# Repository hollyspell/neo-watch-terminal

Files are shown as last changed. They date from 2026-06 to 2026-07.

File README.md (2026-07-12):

# NEO WATCH Terminal

A retro Mission Control–style e-ink terminal that tracks near-Earth objects using NASA's open APIs.

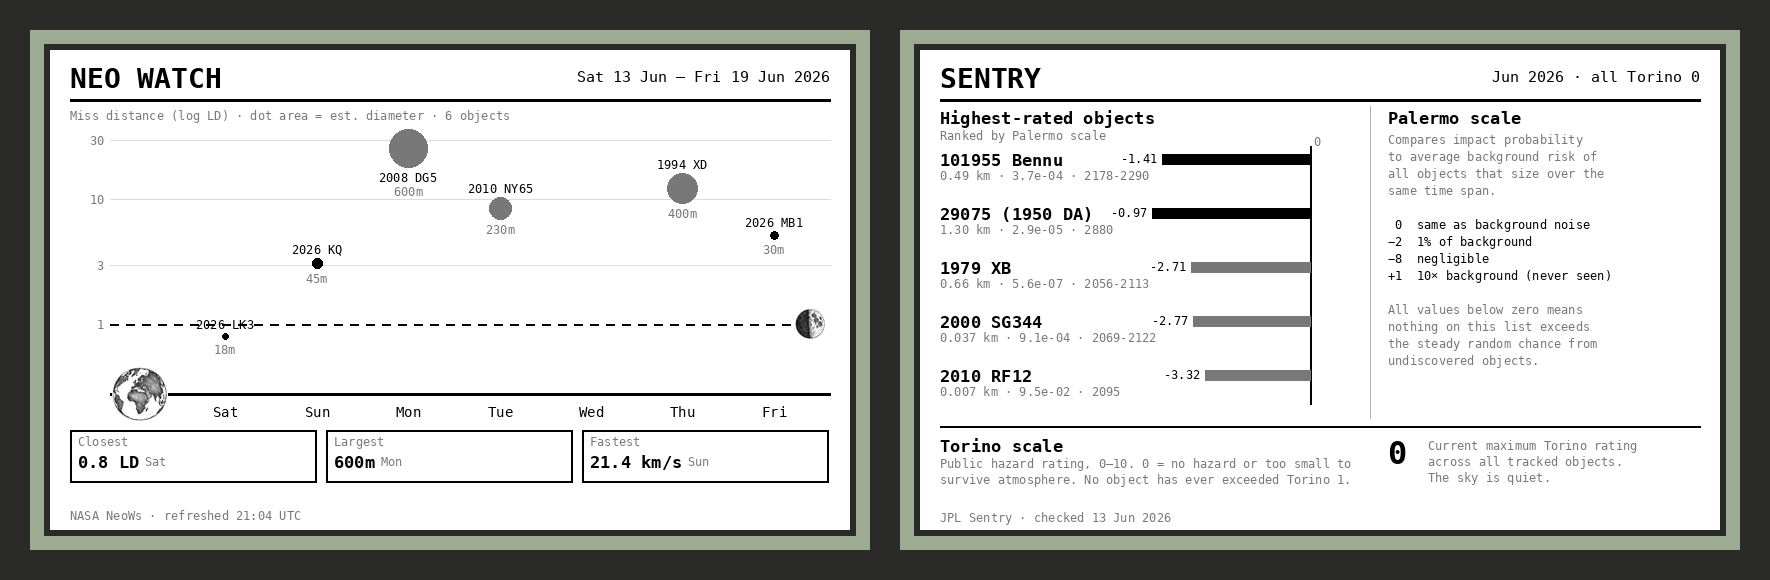
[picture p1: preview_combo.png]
Both screens preview


## What it is

A 3D-printed terminal with a 7.5" e-ink display, powered by a Raspberry Pi Zero, showing two views toggled by a single square push button:

- **NEO WATCH** — this week's asteroid close approaches plotted by distance and day
- **SENTRY** — JPL's impact risk watch list with Palermo and Torino scale ratings

Minimal soldering — four small wire-to-wire joints on the button leads.
Everything else is push-on.

## Quick start

```bash
# On your Pi (after flashing Raspberry Pi OS Lite 32-bit and enabling SPI):
sudo apt install -y git python3-pip python3-pil python3-numpy \
                    python3-rpi.gpio python3-spidev python3-requests \
                    python3-lgpio fonts-dejavu-core

git clone https://github.com/waveshare/e-Paper.git
cd e-Paper/RaspberryPi_JetsonNano/python && pip3 install . --break-system-packages && cd ~

git clone https://github.com/hollyspell/neo-watch-terminal.git
cd neo-watch-terminal

# Get a free key at https://api.nasa.gov — DEMO_KEY is only 30/hr and 50/day
export NASA_API_KEY="your_key_here"

python3 neo_eink.py
```

## Preview without hardware

```bash
# On any computer with Python 3 and Pillow:
pip install pillow requests
python3 neo_eink.py --preview         # live API data → PNG files
python3 neo_eink.py --preview --mock  # mock data → PNG files (no network needed)
```

## Documentation

See the [wiki](../../wiki) for the full build guide:

- [Bill of Materials](../../wiki/Bill-of-Materials) — shopping list with links
- [Printing Guide](../../wiki/Printing-Guide) — STL settings and finishing
- [Hardware Assembly](../../wiki/Hardware-Assembly) — no-solder assembly instructions
- [Software Setup](../../wiki/Software-Setup) — flashing, installing, auto-start
- [Display Design](../../wiki/Display-Design) — visualization design and customization
- [Troubleshooting](../../wiki/Troubleshooting) — common issues and fixes

## Files

| File | Description |
|---|---|
| `neo_eink.py` | Main firmware — fetches APIs, renders views, drives display, handles button |
| `earth_bitmap.png` | Pen-and-ink Earth illustration, pre-processed for e-ink |
| `moon_bitmap.png` | Pen-and-ink Moon illustration, pre-processed for e-ink |
| `terminal.py` | Parametric enclosure generator (Manifold3D + trimesh) |
| `eink_terminal.stl` | Printable enclosure body |
| `eink_plate.stl` | Printable slide-in bottom panel |

## Before you build

Two things that will save you a day:

- **The HAT's Display Config switch must be on `B`** (Interface Config `0`).
  Set wrong, the display runs every demo with zero errors and shows nothing at all.
- **The button goes on GPIO 26, not GPIO 17.** GPIO 17 is the display's reset line.

See [Troubleshooting](../../wiki/Troubleshooting) if the panel stays blank.

## Data sources

- [NASA NeoWs](https://api.nasa.gov/) — near-Earth object close approach data
- [JPL Sentry](https://cneos.jpl.nasa.gov/sentry/) — impact risk monitoring

## License

MIT License

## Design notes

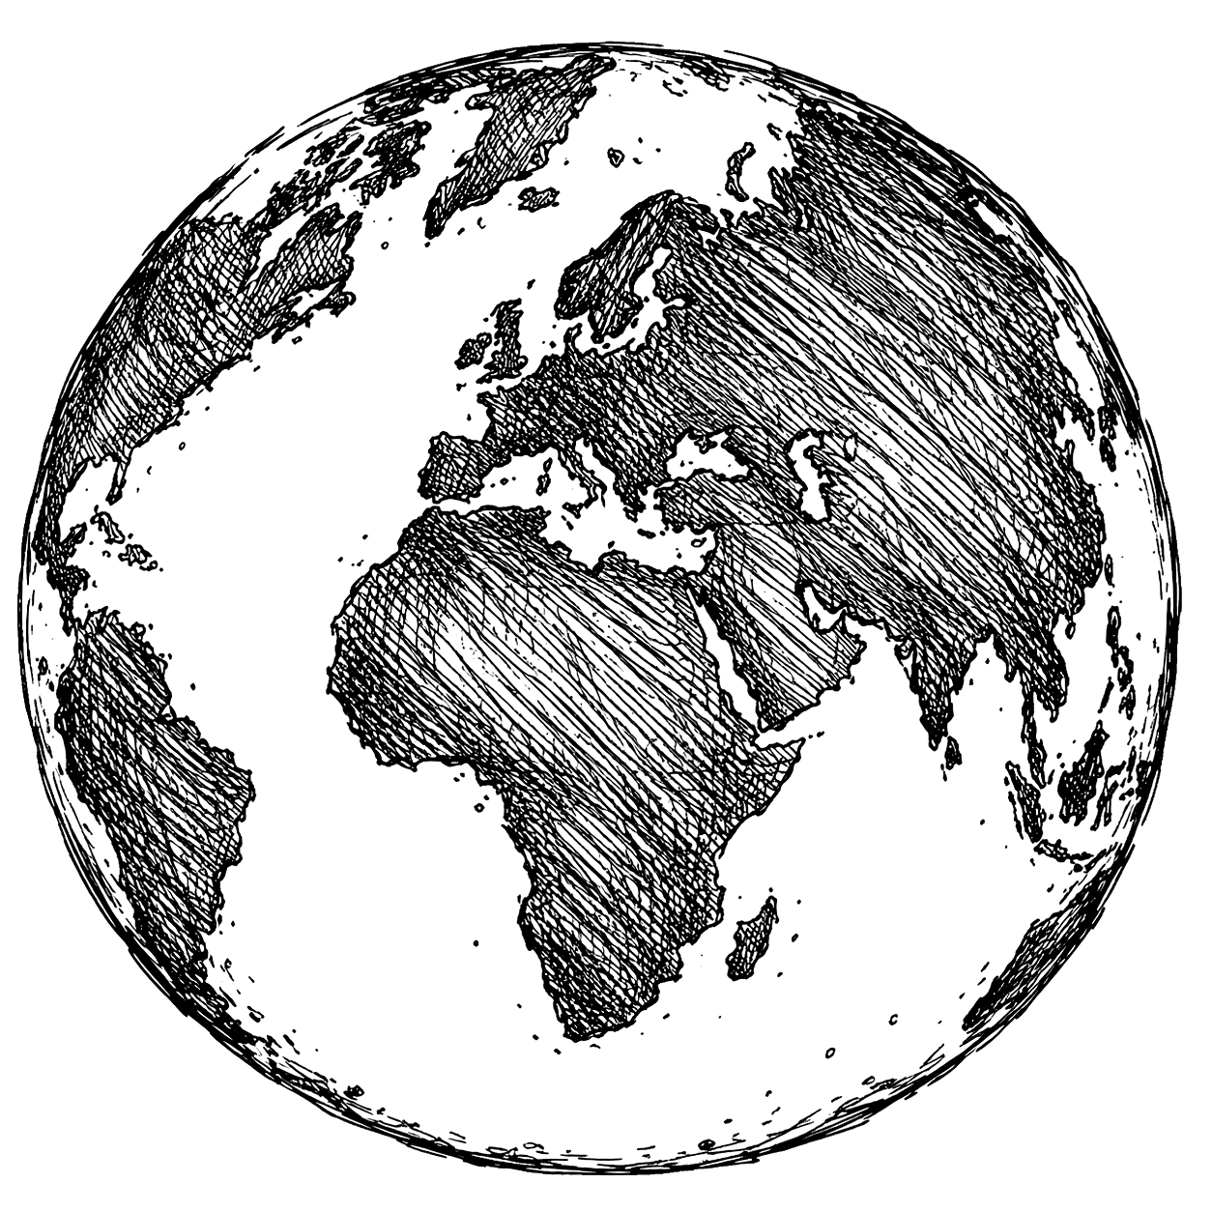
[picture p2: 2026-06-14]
earth_bitmap.png

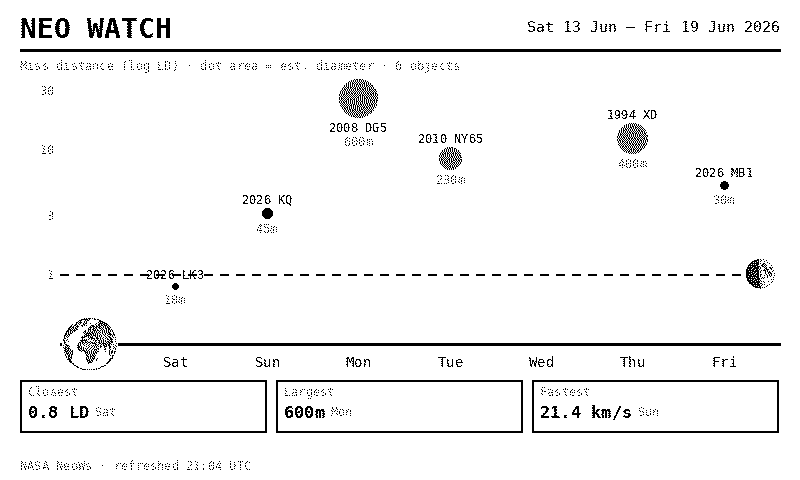
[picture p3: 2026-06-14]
neo_watch_1bit.png

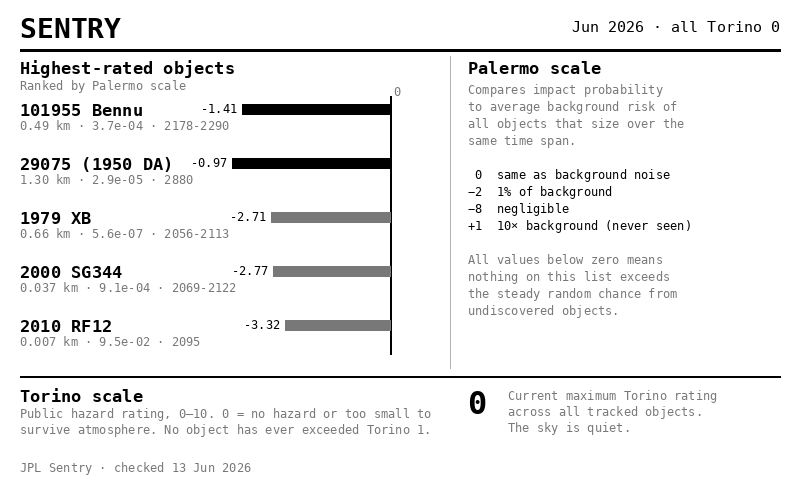
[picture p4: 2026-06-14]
sentry_gray.png

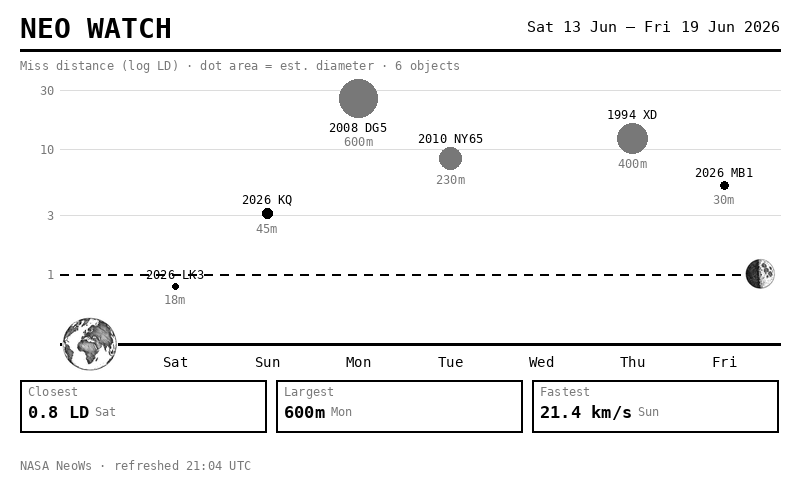
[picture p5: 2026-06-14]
neo_watch_gray.png

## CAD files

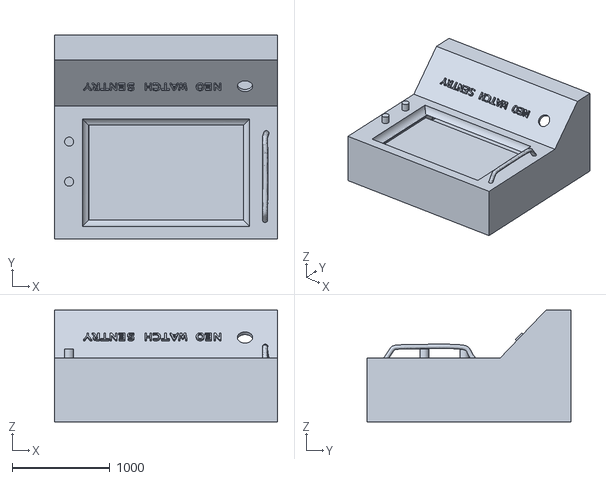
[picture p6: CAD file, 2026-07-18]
terminal test2.stl
2282.6 x 2092.3 x 1143.0

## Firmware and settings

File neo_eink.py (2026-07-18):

#!/usr/bin/env python3
"""
NEO WATCH / SENTRY — dual-view e-ink terminal firmware.

Renders two 800×480 1-bit images for a Waveshare 7.5" e-ink panel:
  View 1: NEO WATCH  — this week's close approaches (NASA NeoWs)
  View 2: SENTRY     — JPL Sentry risk-list objects with Palermo/Torino

Preview mode (no Pi hardware):
    python neo_eink.py --preview

Hardware mode (Raspberry Pi + Waveshare 7.5" v2):
    python neo_eink.py
    (button on GPIO 26 toggles views)

NASA API key: uses DEMO_KEY by default (30 req/hr AND 50 req/day).
Set NASA_API_KEY env var for a free personal key (1000 req/day).
Note: systemd does not read ~/.bashrc — the service unit needs its own
Environment=NASA_API_KEY=... line.
"""

import json, math, os, sys, time, argparse
from datetime import datetime, timedelta
from io import BytesIO
from pathlib import Path

import requests
from PIL import Image, ImageDraw, ImageFont

# ─── Configuration ────────────────────────────────────────────────────
W, H = 800, 480  # Waveshare 7.5" v2 resolution
NASA_KEY = os.environ.get("NASA_API_KEY", "DEMO_KEY")
NEOWS_URL = "https://api.nasa.gov/neo/rest/v1/feed"
_neows_quota = None  # X-RateLimit-Remaining from the most recent NeoWs call
SENTRY_URL = "https://ssd-api.jpl.nasa.gov/sentry.api"

FONT_REG = "/usr/share/fonts/truetype/dejavu/DejaVuSansMono.ttf"
FONT_BOLD = "/usr/share/fonts/truetype/dejavu/DejaVuSansMono-Bold.ttf"

# Preload fonts at sizes we need
def font(size, bold=False):
    return ImageFont.truetype(FONT_BOLD if bold else FONT_REG, size)

F32 = font(28, bold=True)
F20 = font(17)
F20B = font(17, bold=True)
F18 = font(15)
F16 = font(14)
F14 = font(12)
F24 = font(21, bold=True)
F36 = font(32, bold=True)

BLACK = 0
WHITE = 255
GRAY = 30  # dark enough to survive 1-bit dither as readable stipple

# ─── API fetching ─────────────────────────────────────────────────────

def fetch_neows():
    """Fetch this week's near-Earth object close approaches.

    Returns (objects, start, end). `objects` is None on a real failure, or a
    list (possibly empty) on success — the two states render differently.
    """
    today = datetime.utcnow().date()
    end = today + timedelta(days=6)
    params = {
        "start_date": today.isoformat(),
        "end_date": end.isoformat(),
        "api_key": NASA_KEY,
    }
    global _neows_quota
    try:
        r = requests.get(NEOWS_URL, params=params, timeout=30)
        r.raise_for_status()
        data = r.json()
        _neows_quota = r.headers.get("X-RateLimit-Remaining")
        if _neows_quota:
            print(f"  NeoWs quota remaining: {_neows_quota}")
    except Exception as e:
        print(f"NeoWs fetch failed: {e}")
        return None, today, end

    objects = []
    for date_str, neos in data.get("near_earth_objects", {}).items():
        for neo in neos:
            ca = neo["close_approach_data"][0] if neo.get("close_approach_data") else None
            if not ca:
                continue
            dia = neo.get("estimated_diameter", {}).get("meters", {})
            avg_dia = (dia.get("estimated_diameter_min", 0) + dia.get("estimated_diameter_max", 0)) / 2
            miss_ld = float(ca["miss_distance"]["lunar"])
            objects.append({
                "name": neo.get("name", "?").strip("() "),
                "date": date_str,
                "miss_ld": miss_ld,
                "miss_km": float(ca["miss_distance"]["kilometers"]),
                "diameter_m": avg_dia,
                "velocity_kms": float(ca["relative_velocity"]["kilometers_per_second"]),
                "hazardous": neo.get("is_potentially_hazardous_asteroid", False),
            })
    # Keep only passes within 35 LD and sort by date
    objects = [o for o in objects if o["miss_ld"] <= 35]
    objects.sort(key=lambda o: (o["date"], o["miss_ld"]))
    return objects, today, end


def fetch_sentry():
    """Fetch JPL Sentry risk list, sorted by Palermo scale (descending)."""
    try:
        r = requests.get(SENTRY_URL, timeout=30)
        r.raise_for_status()
        data = r.json()
    except Exception as e:
        print(f"Sentry fetch failed: {e}")
        return None

    items = []
    for obj in data.get("data", []):
        ps = float(obj.get("ps_cum") or -99)
        ts = int(float(obj.get("ts_max") or 0))
        dia = obj.get("diameter", "?")
        ip = obj.get("ip", "?")
        name = obj.get("fullname", obj.get("des", "?")).strip()
        yr_range = obj.get("range", "?")
        items.append({
            "name": name,
            "palermo": ps,
            "torino": ts,
            "diameter_km": dia,
            "impact_prob": ip,
            "year_range": yr_range,
        })
    items.sort(key=lambda x: x["palermo"], reverse=True)
    return items


# ─── Drawing helpers ──────────────────────────────────────────────────

# ─── Ink illustration bitmaps for Earth & Moon ────────────────────────

# Pre-processed circular bitmaps from pen-and-ink illustrations
EARTH_BMP = os.path.join(os.path.dirname(__file__), "earth_bitmap.png")
MOON_BMP = os.path.join(os.path.dirname(__file__), "moon_bitmap.png")

_bitmap_cache = {}

def _load_bitmap(bmp_path, size):
    """Load a pre-rendered bitmap and resize to target."""
    key = (bmp_path, size)
    if key in _bitmap_cache:
        return _bitmap_cache[key]
    try:
        img = Image.open(bmp_path).convert("L")
        img = img.resize((size, size), Image.LANCZOS)
    except FileNotFoundError:
        img = Image.new("L", (size, size), WHITE)
        d = ImageDraw.Draw(img)
        d.ellipse([2, 2, size-3, size-3], fill=BLACK)
        print(f"Bitmap not found: {bmp_path} — using fallback")
    _bitmap_cache[key] = img
    return img


def paste_earth(target_img, cx, cy, diameter):
    """Paste the ink-illustration Earth onto a grayscale image."""
    bmp = _load_bitmap(EARTH_BMP, diameter)
    x = cx - diameter // 2
    y = cy - diameter // 2
    target_img.paste(bmp, (x, y))


def paste_moon(target_img, cx, cy, diameter):
    """Paste the ink-illustration Moon, phase-shaded, onto a grayscale image."""
    bmp = apply_moon_phase(_load_bitmap(MOON_BMP, diameter), moon_phase_fraction())
    x = cx - diameter // 2
    y = cy - diameter // 2
    target_img.paste(bmp, (x, y))


# ─── Moon phase (pure math, no API) ──────────────────────────────────

def _julian_day(dt):
    y, m = dt.year, dt.month
    d = dt.day + (dt.hour + dt.minute/60 + dt.second/3600)/24
    if m <= 2:
        y -= 1; m += 12
    a = y // 100
    b = 2 - a + a//4
    return int(365.25*(y+4716)) + int(30.6001*(m+1)) + d + b - 1524.5


def moon_phase_fraction(dt=None):
    """0.0 = new, 0.25 = first quarter, 0.5 = full, 0.75 = last quarter.

    Meeus (Astronomical Algorithms ch.48) low-precision phase angle — accounts
    for the Moon's elliptical orbit, unlike a mean-synodic approximation.
    Accurate to well under 1% illumination. No network required.
    """
    if dt is None:
        dt = datetime.utcnow()
    T = (_julian_day(dt) - 2451545.0) / 36525.0
    D_deg = (297.8501921 + 445267.1114034*T - 0.0018819*T*T) % 360
    M  = math.radians((357.5291092 + 35999.0502909*T - 0.0001536*T*T) % 360)
    Mp = math.radians((134.9633964 + 477198.8675055*T + 0.0087414*T*T) % 360)
    D  = math.radians(D_deg)
    i = (180 - D_deg
         - 6.289*math.sin(Mp) + 2.100*math.sin(M)
         - 1.274*math.sin(2*D - Mp) - 0.658*math.sin(2*D)
         - 0.214*math.sin(2*Mp) - 0.110*math.sin(D)) % 360
    k = (1 + math.cos(math.radians(i))) / 2          # illuminated fraction
    a = math.acos(max(-1.0, min(1.0, 1 - 2*k))) / (2*math.pi)
    return a if D_deg < 180 else 1 - a                # D<180 = waxing

_lit_cache = {}

def _lit_version(moon_img):
    """Sunlit rendering of the moon: craters kept, disk background lifted to white."""
    key = (moon_img.width, moon_img.tobytes())
    if key in _lit_cache:
        return _lit_cache[key]
    size = moon_img.width
    r = size / 2.0
    px = moon_img.load()
    vals = [px[x, y]
            for y in range(size) for x in range(size)
            if (x - r + 0.5)**2 + (y - r + 0.5)**2 < (r - 1)**2]
    if not vals:
        return moon_img
    vals.sort()
    base = vals[len(vals)//2]            # median ≈ the disk's background tone
    T = max(1, int(base * 0.98))
    out = moon_img.point(lambda v: 255 if v >= T else v)
    _lit_cache[key] = out
    return out


def apply_moon_phase(moon_img, fraction):
    """Shade the moon bitmap by phase.

    Sunlit side  → craters on white (the disk's grey background lifted out).
    Shadowed side → the illustration as-is, grey fill and all.
    So a new moon is fully shaded and a full moon is craters on blank white.
    """
    size = moon_img.width
    r = size / 2.0
    shadow = moon_img
    lit = _lit_version(moon_img)

    mask = Image.new("L", (size, size), 0)
    md = ImageDraw.Draw(mask)
    c = math.cos(2 * math.pi * fraction)
    waxing = fraction < 0.5
    for py in range(size):
        y = py - r + 0.5
        if abs(y) >= r:
            continue
        x_e = math.sqrt(r * r - y * y)
        if waxing:
            lit_lo, lit_hi = c * x_e, x_e      # lit on the right
        else:
            lit_lo, lit_hi = -x_e, -c * x_e    # lit on the left
        if lit_hi > lit_lo:
            md.line([(r + lit_lo, py), (r + lit_hi, py)], fill=255)

    out = Image.composite(lit, shadow, mask)
    ImageDraw.Draw(out).ellipse([0, 0, size - 1, size - 1], outline=BLACK, width=1)
    return out

def ld_to_y(ld, y_top, y_bottom):
    """Map lunar distance (log scale) to y pixel. ld in [0.3, 35] → [y_bottom, y_top]."""
    if ld <= 0:
        ld = 0.3
    log_min, log_max = math.log10(0.3), math.log10(35)
    frac = (math.log10(ld) - log_min) / (log_max - log_min)
    return int(y_bottom - frac * (y_bottom - y_top))


def dia_to_radius(dia_m):
    """Object diameter (meters) → dot radius in pixels (sqrt scale, clamped)."""
    r = max(3, min(22, int(2.5 * math.sqrt(dia_m / 10))))
    return r


# ─── View 1: NEO WATCH ───────────────────────────────────────────────

def render_neo_watch(objects, date_start, date_end):
    img = Image.new("L", (W, H), WHITE)
    draw = ImageDraw.Draw(img)

    # ── Header ──
    draw.text((20, 12), "NEO WATCH", font=F32, fill=BLACK)
    date_str = f"{date_start.strftime('%a %d %b')} – {date_end.strftime('%a %d %b %Y')}"
    bbox = draw.textbbox((0, 0), date_str, font=F18)
    draw.text((W - 20 - (bbox[2] - bbox[0]), 18), date_str, font=F18, fill=BLACK)
    draw.line([(20, 50), (W-20, 50)], fill=BLACK, width=3)

    # ── Subtitle ──
    count = len(objects) if objects else 0
    sub = f"Miss distance (log LD) · dot area = est. diameter · {count} objects"
    draw.text((20, 58), sub, font=F14, fill=GRAY)

    # ── Chart area ──
    chart_left = 60
    chart_right = W - 20
    chart_top = 82
    chart_bot = 340
    earth_x = chart_left + 30

    # Grid lines
    for ld_val, label in [(30, "30"), (10, "10"), (3, "3")]:
        y = ld_to_y(ld_val, chart_top, chart_bot)
        draw.line([(chart_left, y), (chart_right, y)], fill=220, width=1)
        bbox = draw.textbbox((0, 0), label, font=F14)
        draw.text((chart_left - 6 - (bbox[2]-bbox[0]), y - 7), label, font=F14, fill=GRAY)

    # Moon line at 1 LD
    moon_y = ld_to_y(1.0, chart_top, chart_bot)
    # Dashed line
    dash_len = 8
    for x in range(chart_left, chart_right, dash_len * 2):
        draw.line([(x, moon_y), (min(x + dash_len, chart_right), moon_y)], fill=BLACK, width=2)
    draw.text((chart_left - 6 - draw.textbbox((0,0), "1", font=F14)[2], moon_y - 7),
              "1", font=F14, fill=GRAY)

    # Earth baseline
    draw.line([(chart_left, chart_bot + 4), (chart_right, chart_bot + 4)], fill=BLACK, width=3)

    # Draw Earth
    paste_earth(img, earth_x, chart_bot + 4, 56)

    # Draw Moon
    moon_x = chart_right - 20
    paste_moon(img, moon_x, moon_y, 32)

    # ── Day columns ──
    if objects and date_start:
        days = [(date_start + timedelta(days=i)) for i in range(7)]
        day_labels = [d.strftime("%a") for d in days]
        day_strs = [d.isoformat() for d in days]

        col_width = (chart_right - chart_left - 80) / 7  # leave room for earth & moon
        col_starts = [chart_left + 70 + int(i * col_width + col_width / 2) for i in range(7)]

        # Day labels below baseline
        for i, (lbl, cx) in enumerate(zip(day_labels, col_starts)):
            bbox = draw.textbbox((0, 0), lbl, font=F16)
            draw.text((cx - (bbox[2]-bbox[0])//2, chart_bot + 14), lbl, font=F16, fill=BLACK)

        # Plot objects — group by day, jitter within column if needed
        day_objects = {ds: [] for ds in day_strs}
        for obj in objects:
            if obj["date"] in day_objects:
                day_objects[obj["date"]].append(obj)

        for i, ds in enumerate(day_strs):
            objs = day_objects.get(ds, [])
            cx = col_starts[i]
            for j, obj in enumerate(objs):
                y = ld_to_y(obj["miss_ld"], chart_top, chart_bot)
                r = dia_to_radius(obj["diameter_m"])
                # Jitter horizontally if multiple on same day
                jitter = (j - len(objs)/2) * (r + 4) if len(objs) > 1 else 0
                ox = int(cx + jitter)
                oy = y

                fill = GRAY if obj.get("hazardous") else BLACK
                draw.ellipse([ox-r, oy-r, ox+r, oy+r], fill=fill)

                # Label — short name
                name = obj["name"]
                # Shorten long names
                if len(name) > 10:
                    parts = name.split()
                    name = parts[-1] if len(parts) > 1 else name[:8]
                bbox = draw.textbbox((0, 0), name, font=F14)
                tw = bbox[2] - bbox[0]
                label_y = oy - r - 16
                if label_y < chart_top:
                    label_y = oy + r + 3
                draw.text((ox - tw//2, label_y), name, font=F14, fill=BLACK)

                # Size label below
                if obj["diameter_m"] >= 10:
                    size_str = f"{int(obj['diameter_m'])}m"
                    bbox2 = draw.textbbox((0, 0), size_str, font=F14)
                    sw = bbox2[2] - bbox2[0]
                    sz_y = oy + r + 3
                    if label_y == oy + r + 3:
                        sz_y = label_y + 14
                    if sz_y < chart_bot - 2:
                        draw.text((ox - sw//2, sz_y), size_str, font=F14, fill=GRAY)
    else:
        # Distinguish "the sky was quiet" from "the fetch actually failed".
        # fetch_neows() returns None on failure, [] on a successful quiet week.
        if objects is None:
            msg = "No data — check API"
        else:
            msg = "No close approaches this week"
        bbox = draw.textbbox((0, 0), msg, font=F20)
        draw.text(((W - (bbox[2]-bbox[0])) // 2, 200), msg, font=F20, fill=BLACK)

    # ── Stat boxes ──
    box_y = chart_bot + 40
    box_h = 52
    box_w = (W - 60) // 3

    stats = _compute_stats(objects)
    for i, (label, value, sub) in enumerate(stats):
        bx = 20 + i * (box_w + 10)
        draw.rectangle([bx, box_y, bx + box_w, box_y + box_h], outline=BLACK, width=2)
        draw.text((bx + 8, box_y + 4), label, font=F14, fill=GRAY)
        draw.text((bx + 8, box_y + 22), value, font=F20B, fill=BLACK)
        # Sub text (day) to right of value
        vbbox = draw.textbbox((0, 0), value, font=F20B)
        draw.text((bx + 14 + (vbbox[2]-vbbox[0]), box_y + 24), sub, font=F14, fill=GRAY)

    # ── Footer ──
    footer = "NASA NeoWs · refreshed " + time.strftime("%H:%M %Z")
    if _neows_quota:
        footer += f" · {_neows_quota} API calls left today"
    draw.text((20, H - 22), footer, font=F14, fill=GRAY)

    return img


def _compute_stats(objects):
    if not objects:
        return [("Closest", "—", ""), ("Largest", "—", ""), ("Fastest", "—", "")]
    closest = min(objects, key=lambda o: o["miss_ld"])
    largest = max(objects, key=lambda o: o["diameter_m"])
    fastest = max(objects, key=lambda o: o["velocity_kms"])
    c_day = datetime.fromisoformat(closest["date"]).strftime("%a")
    l_day = datetime.fromisoformat(largest["date"]).strftime("%a")
    f_day = datetime.fromisoformat(fastest["date"]).strftime("%a")
    return [
        ("Closest", f"{closest['miss_ld']:.1f} LD", c_day),
        ("Largest", f"{int(largest['diameter_m'])}m", l_day),
        ("Fastest", f"{fastest['velocity_kms']:.1f} km/s", f_day),
    ]


# ─── View 2: SENTRY ──────────────────────────────────────────────────

def fmt_ip(ip_raw):
    """Impact probability -> compact scientific notation, e.g. 5.7e-04."""
    try:
        return f"{float(ip_raw):.1e}"
    except (TypeError, ValueError):
        return "?"


def fmt_years(yr):
    """Collapse degenerate ranges: '2880-2880' -> '2880'."""
    if isinstance(yr, str) and "-" in yr:
        a, b = yr.split("-", 1)
        if a.strip() == b.strip():
            return a.strip()
    return yr


def render_sentry(items):
    img = Image.new("L", (W, H), WHITE)
    draw = ImageDraw.Draw(img)

    max_torino = 0
    if items:
        max_torino = max(it["torino"] for it in items)
    draw.text((20, 12), "SENTRY", font=F32, fill=BLACK)
    torino_str = time.strftime("%b %Y") + f" · all Torino {max_torino}"
    bbox = draw.textbbox((0, 0), torino_str, font=F18)
    draw.text((W - 20 - (bbox[2]-bbox[0]), 18), torino_str, font=F18, fill=BLACK)
    draw.line([(20, 50), (W-20, 50)], fill=BLACK, width=3)

    # ── Left panel: ranked objects ──
    mid_x = 450
    draw.text((20, 58), "Highest-rated objects", font=F20B, fill=BLACK)
    draw.text((20, 78), "Ranked by Palermo scale", font=F14, fill=BLACK)

    # Bar lane: names own [20, name_right]; bars own their own lane after it
    name_right = 250
    bar_lane_left = name_right + 60   # room for value labels left of short bars
    zero_x = mid_x - 20
    bar_max = zero_x - bar_lane_left
    bar_top = 100
    bar_spacing = 54

    n_show = min(5, len(items) if items else 0)
    if n_show > 0:
        draw.line([(zero_x, bar_top - 4), (zero_x, bar_top + n_show * bar_spacing - 16)],
                  fill=BLACK, width=2)
        draw.text((zero_x + 4, bar_top - 16), "0", font=F14, fill=BLACK)

    top_items = items[:n_show] if items else []
    for i, it in enumerate(top_items):
        y = bar_top + i * bar_spacing
        # Name — shrink to fit its column, truncate only as last resort
        name = it["name"]
        f_name = F20B
        if draw.textbbox((0, 0), name, font=f_name)[2] > name_right - 20:
            f_name = F16
            while name and draw.textbbox((0, 0), name, font=f_name)[2] > name_right - 20:
                name = name[:-1]
        draw.text((20, y), name, font=f_name, fill=BLACK)
        # Details line
        dia_str = it["diameter_km"]
        if isinstance(dia_str, str):
            detail = f"{dia_str} km"
        else:
            detail = f"{float(dia_str):.2f} km"
        detail += f" · {fmt_ip(it['impact_prob'])} · {fmt_years(it['year_range'])}"
        draw.text((20, y + 18), detail, font=F14, fill=BLACK)

        # Palermo bar — grows LEFT from zero_x, clamped to its lane
        ps = it["palermo"]
        bar_len = max(4, min(bar_max, int((ps + 8) / 8 * bar_max)))
        bar_left = zero_x - bar_len
        fill_c = BLACK if ps > -2 else GRAY
        draw.rectangle([bar_left, y + 4, zero_x, y + 14], fill=fill_c)
        ps_str = f"{ps:.2f}"
        bbox = draw.textbbox((0, 0), ps_str, font=F14)
        draw.text((bar_left - (bbox[2]-bbox[0]) - 5, y + 1), ps_str, font=F14, fill=BLACK)

    if not items:
        draw.text((20, 110), "No data — check API", font=F20, fill=BLACK)

    # ── Vertical divider ──
    draw.line([(mid_x, 56), (mid_x, 368)], fill=180, width=1)

    # ── Right panel: scale explanations ──
    rx = mid_x + 18

    draw.text((rx, 58), "Palermo scale", font=F20B, fill=BLACK)
    palermo_lines = [
        "Compares impact probability",
        "to average background risk of",
        "all objects that size over the",
        "same time span.",
        "",
        " 0  same as background noise",
        "−2  1% of background",
        "−8  negligible",
        "+1  10× background (never seen)",
        "",
        "All values below zero means",
        "nothing on this list exceeds",
        "the steady random chance from",
        "undiscovered objects.",
    ]
    for j, line in enumerate(palermo_lines):
        y = 82 + j * 17
        if line == "":
            continue
        draw.text((rx, y), line, font=F14, fill=BLACK)

    # ── Torino section ──
    draw.line([(20, 376), (W-20, 376)], fill=BLACK, width=2)

    draw.text((20, 386), "Torino scale", font=F20B, fill=BLACK)
    torino_lines = [
        "Public hazard rating, 0–10. 0 = no hazard or too small to",
        "survive atmosphere. No object has ever exceeded Torino 1.",
    ]
    for j, line in enumerate(torino_lines):
        draw.text((20, 406 + j * 16), line, font=F14, fill=BLACK)

    # Big Torino number
    draw.text((rx, 384), str(max_torino), font=F36, fill=BLACK)
    t_lines = [
        "Current maximum Torino rating",
        "across all tracked objects.",
        "The sky is quiet.",
    ]
    for j, line in enumerate(t_lines):
        draw.text((rx + 40, 388 + j * 16), line, font=F14, fill=BLACK)

    # Footer
    draw.text((20, H - 20),
              "JPL Sentry · checked " + time.strftime("%d %b %Y"),
              font=F14, fill=BLACK)

    return img


# ─── 1-bit conversion (Floyd-Steinberg dither) ───────────────────────

def to_1bit(img):
    """Convert grayscale image to 1-bit with Floyd-Steinberg dithering."""
    return img.convert("1")


# ─── Hardware driver (Waveshare 7.5" v2) ─────────────────────────────
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

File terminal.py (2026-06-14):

"""
Retro terminal enclosure for a 7.5" e-ink display (Waveshare-style).
Coordinate system while building: x = depth (front->back), y = height, z = width.
Rotated at the end so Z is up for printing.
Units: mm
"""
import math
import numpy as np
from manifold3d import Manifold, CrossSection, JoinType
import trimesh

# ---------------- Parameters ----------------
W = 186.0          # overall width
D = 110.0          # overall depth
H = 215.0          # overall height
T = 4.0            # wall thickness

# E-ink panel (from outline drawing)
PANEL_W, PANEL_H = 170.20, 111.20      # outer glass
VIEW_W,  VIEW_H  = 163.20, 97.92       # active area
POCKET_W = PANEL_W + 1.3               # clearance pocket behind bezel
POCKET_H = PANEL_H + 1.3
OPEN_W   = VIEW_W - 2.0                # window slightly smaller than active area
OPEN_H   = VIEW_H - 2.0
BEZEL_T  = 2.0                         # lip the panel sits against

# Cord exit
CORD_D = 12.0

# Side profile (x = depth, y = height), CCW
FACE_X   = 55.0    # x position of the vertical screen face
FACE_LO  = 70.0    # bottom of screen face
FACE_HI  = 205.0   # top of screen face
profile = [
    (0.0,    0.0),
    (D,      0.0),
    (D,      H),
    (75.0,   H),          # flat top
    (FACE_X, FACE_HI),    # chamfer down to screen face
    (FACE_X, FACE_LO),    # vertical screen face
    (0.0,    25.0),       # slanted button panel down to front lip
]

# ---------------- Slide-in panel parameters ----------------
RAIL_W = 4.0          # rail width (inward from wall)
RAIL_H = 3.0          # rail height
RAIL_INSET = 8.0      # inset from inner wall to rail
PLATE_T = 2.5         # plate thickness
PLATE_CLEARANCE = 0.4 # side clearance for plate
DETENT_H = 0.8        # locking bump height
DETENT_W = 6.0        # locking bump width along rail
DETENT_POS = 20.0     # distance from back wall to detent center

# Derived
INNER_W = W - 2 * T                    # inner cavity width
PLATE_W = INNER_W - 2 * PLATE_CLEARANCE  # plate width
PLATE_D = D - 2 * T - 2.0              # plate depth (slight clearance front/back)

# ---------------- Outer shell ----------------
outer = CrossSection([profile]).extrude(W)
inner = CrossSection([profile]).offset(-T, JoinType.Miter).extrude(W - 2 * T).translate([0, 0, T])
body = outer - inner

# Open entire bottom for slide-in panel
bottom_open = Manifold.cube([D - 16, 10, W - 16]).translate([8, -2, 8])
body -= bottom_open

# ---------------- Rails for slide-in panel ----------------
# Two rails running front-to-back on the inner bottom, inset from side walls
# Left rail (low z side)
rail_z_left = T + RAIL_INSET
rail_left = Manifold.cube([PLATE_D + 4, RAIL_H, RAIL_W]).translate([T - 1, T, rail_z_left])
body += rail_left

# Right rail (high z side)
rail_z_right = W - T - RAIL_INSET - RAIL_W
rail_right = Manifold.cube([PLATE_D + 4, RAIL_H, RAIL_W]).translate([T - 1, T, rail_z_right])
body += rail_right

# Locking detent bumps on top of each rail
for rz in [rail_z_left, rail_z_right]:
    bump = Manifold.cube([DETENT_W, DETENT_H, RAIL_W]).translate([
        D - T - DETENT_POS - DETENT_W / 2,  # near back
        T + RAIL_H,                            # on top of rail
        rz
    ])
    body += bump

# Front lip / stop — small blocks at the front of each rail to guide the plate
for rz in [rail_z_left, rail_z_right]:
    guide = Manifold.cube([3, RAIL_H + PLATE_T + 1, RAIL_W]).translate([
        T - 1, T, rz
    ])
    # Don't add these — they'd block the plate from sliding in
    # Instead the front wall lip serves as the stop

# ---------------- Screen window + pocket ----------------
cy = (FACE_LO + FACE_HI) / 2.0          # screen center height
cz = W / 2.0

window = Manifold.cube([T + 4, OPEN_H, OPEN_W], True).translate([FACE_X + T / 2, cy, cz])
pocket = Manifold.cube([T, POCKET_H, POCKET_W], True).translate(
    [FACE_X + BEZEL_T + T / 2, cy, cz])     # starts 2 mm behind the front surface
body = body - window - pocket

# ---------------- Button hole (slanted panel) ----------------
# 16mm round mounting hole for the square-cap momentary button
panel_ang = math.degrees(math.atan2(70 - 25, FACE_X))
BTN_R = 16.0 / 2 + 0.2
btn_cut = Manifold.cylinder(30, BTN_R, circular_segments=64)
btn_cut = btn_cut.rotate([0, 0, panel_ang + 90])
btn_cut = btn_cut.translate([27.5, 47.5, cz - 55.0])
body -= btn_cut

# ---------------- Cord hole (back, near bottom) ----------------
cord = Manifold.cylinder(T + 6, CORD_D / 2, circular_segments=64)
cord = cord.rotate([0, 90, 0]).translate([D - T - 3, 22.0, cz])
body -= cord

# ---------------- Vent slots (back wall) ----------------
for off in (36.0, 56.0, 76.0):
    slot = Manifold.cube([T + 6, 50, 6], True).translate([D - T / 2, 55.0, cz + off])
    body -= slot

# ================ SLIDE-IN PLATE (separate piece) ================
plate = Manifold.cube([PLATE_D, PLATE_T, PLATE_W]).translate([
    T + 1,                      # x: starts just inside front wall
    T + RAIL_H,                 # y: sits on top of rails
    T + PLATE_CLEARANCE         # z: centered with clearance
])

# Vent slots in the back 2/3 of the plate
vent_region_start = D / 3           # front 1/3 is solid (finger grip area)
vent_slot_w = 4.0
vent_gap = 8.0
n_vent_rows = 5
n_vent_cols = int((PLATE_W - 40) / (vent_slot_w + vent_gap))
vent_start_z = T + PLATE_CLEARANCE + 20  # inset from plate edges

for row in range(n_vent_rows):
    vx = vent_region_start + 10 + row * 14
    for col in range(n_vent_cols):
        vz = vent_start_z + col * (vent_slot_w + vent_gap)
        vent = Manifold.cube([10, PLATE_T + 2, vent_slot_w]).translate([
            vx, T + RAIL_H - 1, vz
        ])
        plate -= vent

# Detent notches on underside of plate (matching the rail bumps)
for rz_offset in [RAIL_INSET, INNER_W - RAIL_INSET - RAIL_W]:
    notch = Manifold.cube([DETENT_W + 0.6, DETENT_H + 0.4, RAIL_W + 0.6]).translate([
        D - T - DETENT_POS - DETENT_W / 2 - 0.3,
        T + RAIL_H - DETENT_H - 0.2,
        T + rz_offset - 0.3
    ])
    plate -= notch

# Finger notch at front edge of plate for easy removal
finger = Manifold.cylinder(20, 8, circular_segments=32)
finger = finger.rotate([90, 0, 0])
finger = finger.translate([T + 1, T + RAIL_H + PLATE_T / 2, W / 2])
plate -= finger

# ================ Orient and export ================
# Rotate both so Z is up for printing
body = body.rotate([90, 0, 0]).translate([0, W, 0])
plate = plate.rotate([90, 0, 0]).translate([0, W, 0])

# Export main body
mesh = body.to_mesh()
tm = trimesh.Trimesh(vertices=np.asarray(mesh.vert_properties)[:, :3],
                     faces=np.asarray(mesh.tri_verts))
print("Body — watertight:", tm.is_watertight, "| volume cm^3:", round(tm.volume / 1000, 1))
print("  bounds (mm):", np.round(tm.bounds, 1).tolist())
tm.export("/home/claude/eink_terminal.stl")
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

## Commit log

2026-06-20 Change GPIO button pin from 17 to 26
2026-06-20 Add button press test using gpiozero library
2026-07-04 Handle missing ts_max value in neo_eink.py
    [neo_eink.py]
2026-07-12 Revise README for soldering, installation, and troubleshooting
    Updated soldering instructions and installation commands in the README. Changed repository URLs and added troubleshooting notes.
2026-07-18 Enhance NASA API key handling and improve docstrings
    Updated NASA API key usage information and improved docstrings for clarity. Adjusted error handling and rendering logic for better functionality.
    [neo_eink.py]
2026-07-18 Add files via upload
    updated stl file for enclosure to final iteration
    [terminal test2.stl]
